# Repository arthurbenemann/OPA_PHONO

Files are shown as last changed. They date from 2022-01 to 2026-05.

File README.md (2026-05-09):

# OPA_PHONO

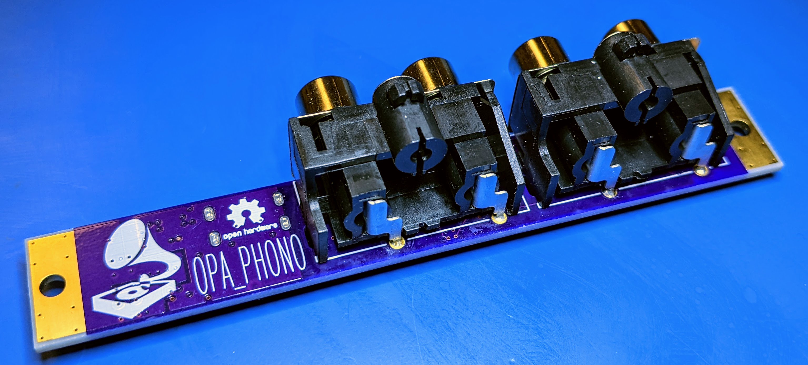
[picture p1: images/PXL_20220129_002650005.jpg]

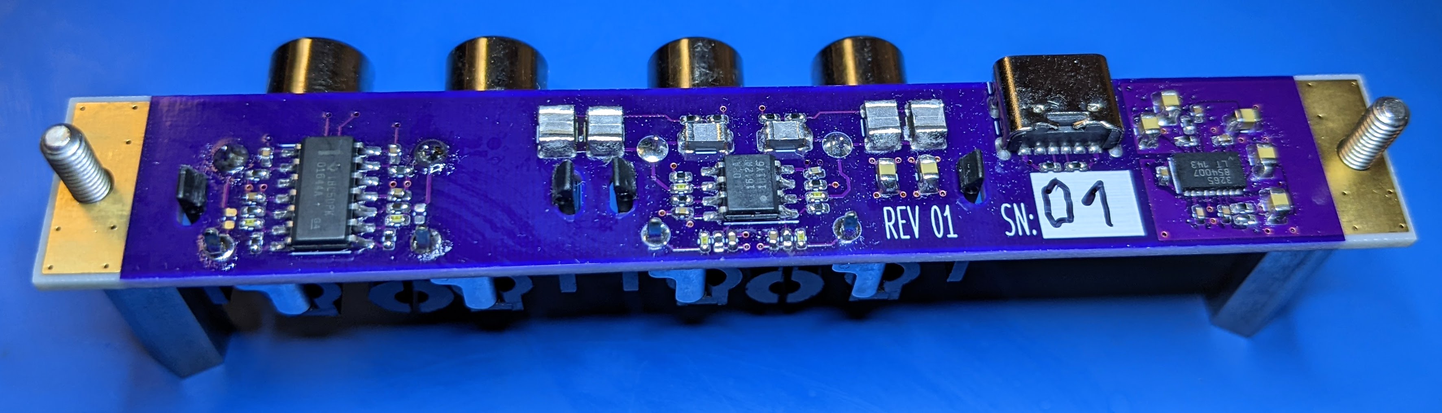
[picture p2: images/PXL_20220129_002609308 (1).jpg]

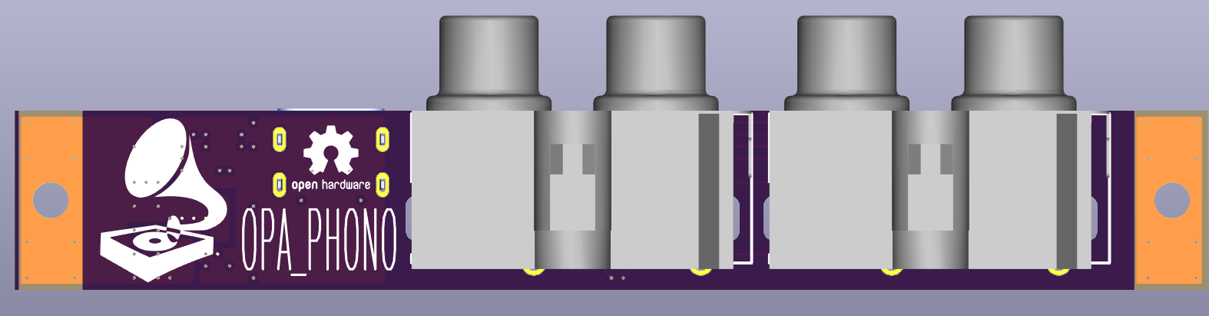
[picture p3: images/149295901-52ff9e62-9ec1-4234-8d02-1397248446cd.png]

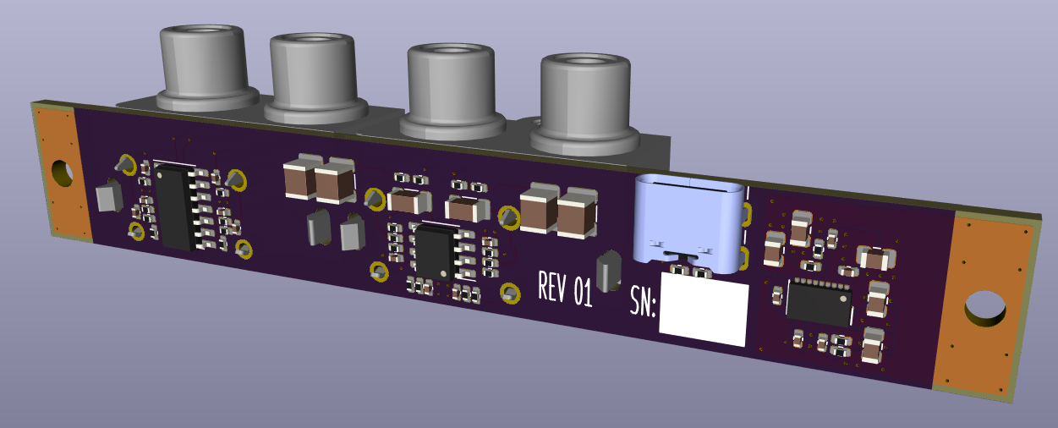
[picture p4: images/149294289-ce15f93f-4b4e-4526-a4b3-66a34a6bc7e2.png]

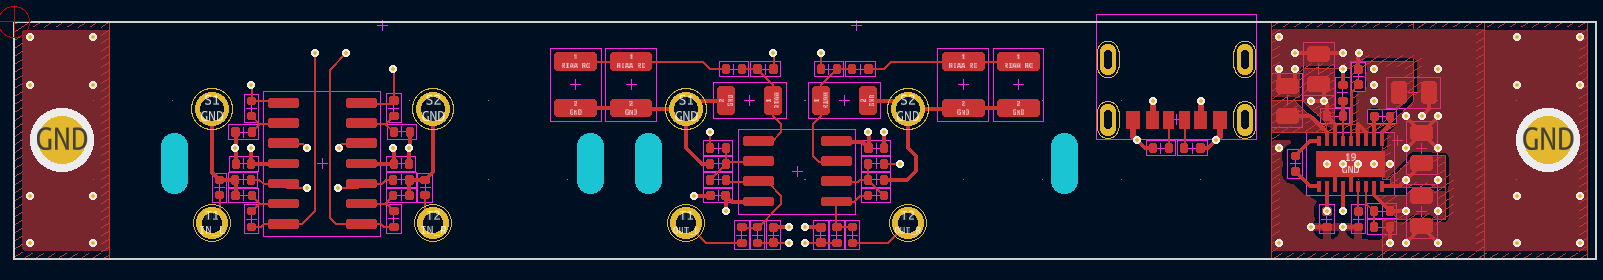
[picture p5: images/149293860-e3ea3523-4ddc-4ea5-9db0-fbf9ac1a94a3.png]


## RIAA filter Simulation
Overall response with (blue) and without(green) cartridge model:
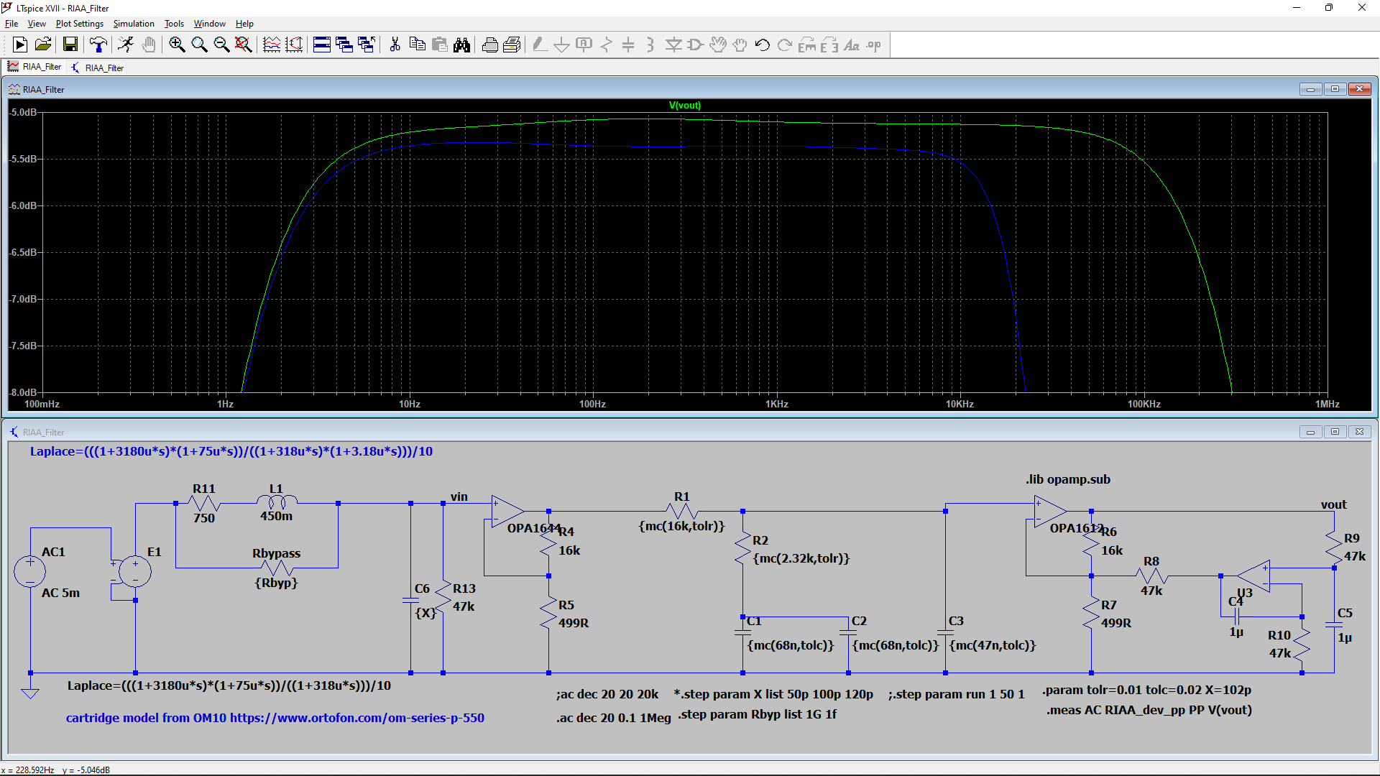
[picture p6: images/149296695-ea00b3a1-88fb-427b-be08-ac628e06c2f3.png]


RIAA Filter deviation assuming 2% capacitors and 1% resistors
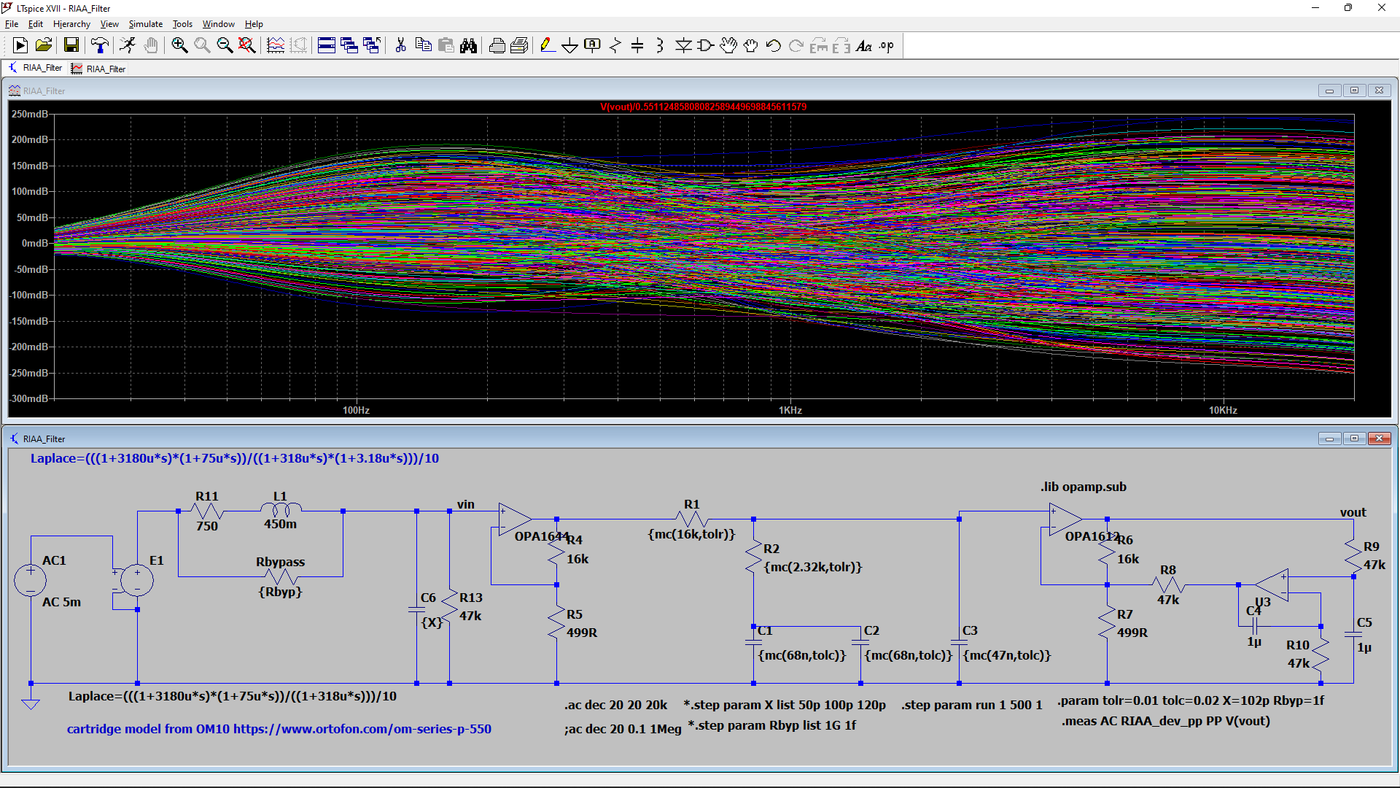
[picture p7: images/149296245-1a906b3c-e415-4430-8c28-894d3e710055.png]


## Mechanical Enclosure

### Hammond case
The CAD model is avaliable in Fusion360 at: https://a360.co/32rnA34.  I may design a faceplate PCB with graphics, but in the meantime the Hammond 1544L80 enclosure can be milled acording to the drawings at [OPA_PHONO_FACEPLATE.pdf](/Enclosure/OPA_PHONO_FACEPLATE.pdf). A compatible drawing with slighly larger holes, but more avaliable sizes is on the bottom drawing.

### 3D printed case
Mell, has created a 3d printed case for his build. Files stored under [Enclosure-3dprint/](./Enclosure-3dprint/)

## Measurements

**SN01** deviation from RIAA curve, based on measurements [SN01_REW.mdat](Measurements/SN01_REW.mdat). Note very close to noise floor at 15kHz, 60Hz hum and harmonics distorting measurement, low frequency behavior from testing equipment. 

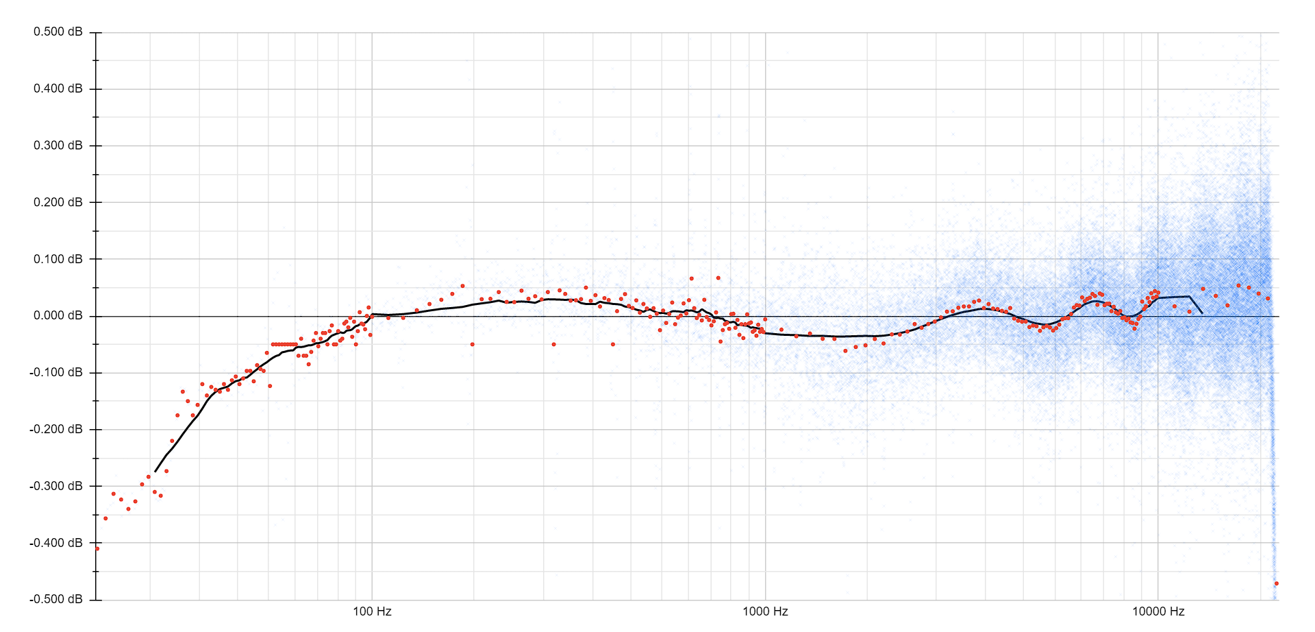
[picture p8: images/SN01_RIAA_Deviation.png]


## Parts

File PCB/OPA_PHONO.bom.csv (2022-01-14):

Designator | Description | MPN | Manufacturer | Qty
C2, C3, C8, C9 | CAP FILM 0.068UF 2% 16VDC 1210 | ECH-U1C683GX5 | Panasonic Electronic Components | 4
C4, C10 | CAP FILM 0.047UF 2% 16VDC 1206 | ECH-U1C473GX5 | Panasonic Electronic Components | 2
C5, C6, C11-C14, C16-C22 | CAP CER 1UF 25V X5R 0402 | GRM155R61E105KA12D | Murata Electronics | 13
C15, C23-C28 | CAP CER 10UF 16V X5R 0805 | GRM21BR61C106KE15L | Murata Electronics | 7
J1, J2 | CONN DUAL RCA JACK MONO 3.2MM R/A | PJRAS2X1S01X | Switchcraft Inc. | 2
J3 | CONN RCPT TYPE C 24POS SMD RA | UJC-HP-3-SMT-TR | CUI Devices | 1
N1 | BOX ALUM NATURAL 3.15"LX4.05"W | 1455L801 | Hammond Manufacturing | 1
R5, R17 | RES SMD 2.32K OHM 1% 1/16W 0402 | RT0402FRE072K32L | YAGEO | 2
R2, R4, R7, R14, R16, R19 | RES SMD 16K OHM 1% 1/16W 0402 | RT0402FRE0716KL | YAGEO | 6
R3, R6, R8, R12, R15, R24 | RES SMD 499R OHM 1% 1/16W 0402 | RT0402FRE07499RL | YAGEO | 6
R1, R9-R11, R13, R21-R23 | RES SMD 47K OHM 1% 1/16W 0402 | RT0402FRE0747KL | YAGEO | 8
R25, R28 | RES 20.5K OHM 1% 1/16W 0402 | RC0402FR-0720K5L | YAGEO | 2
R26, R27, R29, R30 | RES SMD 5.1K OHM 1% 1/16W 0402 | RC0402FR-075K1L | YAGEO | 4
U1 | IC AUDIO 4 CIRCUIT 14SOIC | OPA1644AID | Texas Instruments | 1
U2 | IC AUDIO 2 CIRCUIT 8SOIC | OPA1612AID | Texas Instruments | 1
U3 | IC REG CHARGE PUMP INV 18DFN | LTC3265EDHC#TRPBF | Analog Devices Inc. | 1

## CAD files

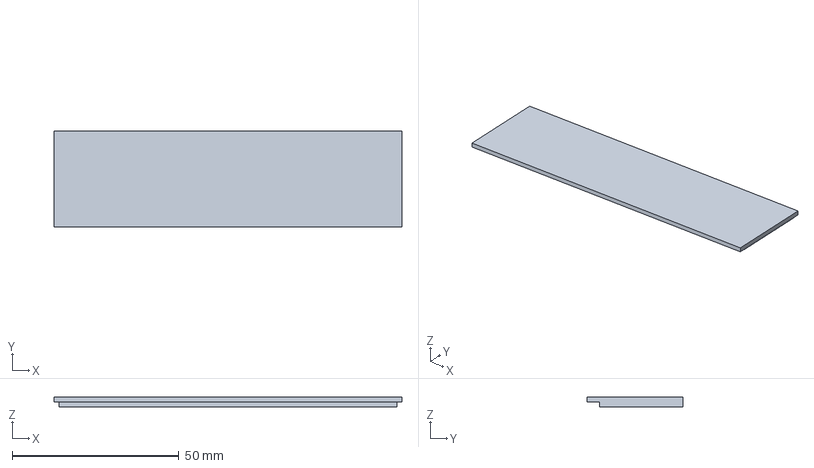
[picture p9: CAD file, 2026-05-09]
Enclosure-3dprint/Preamp Cover-Body.3mf
104.5 x 28.8 x 2.90 mm

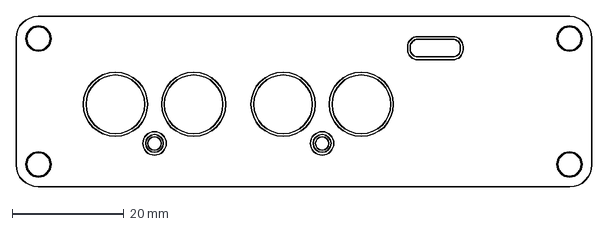
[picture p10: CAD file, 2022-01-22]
Enclosure/front_pannel.dxf
103.0 x 30.5 mm

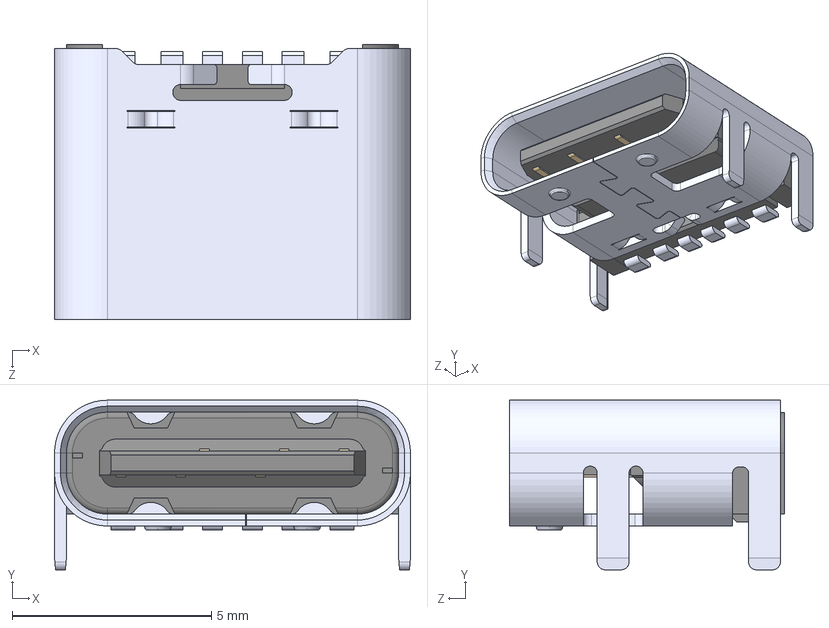
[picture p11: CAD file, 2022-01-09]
PCB/UJC-HP-3-SMT-TR.step
8.94 x 4.26 x 6.90 mm

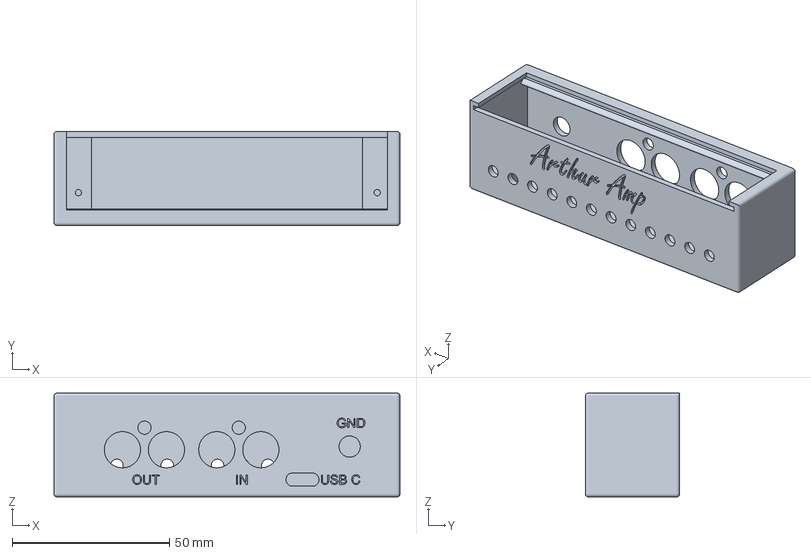
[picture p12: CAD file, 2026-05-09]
Enclosure-3dprint/Phono Preamp Box-Body.3mf
110.0 x 30.0 x 33.0 mm

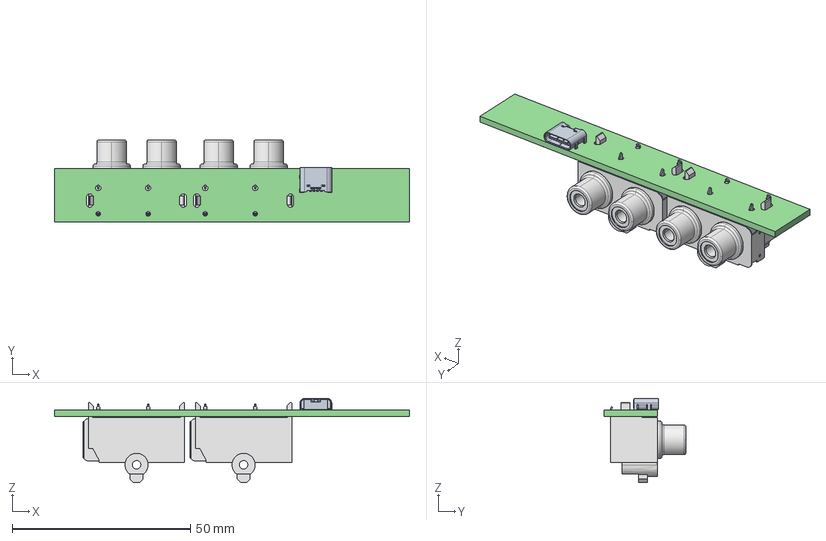
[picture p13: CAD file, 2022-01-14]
Enclosure/OPA_PHONO.step
99.5 x 23.0 x 23.6 mm
OPA_PHONO PCB

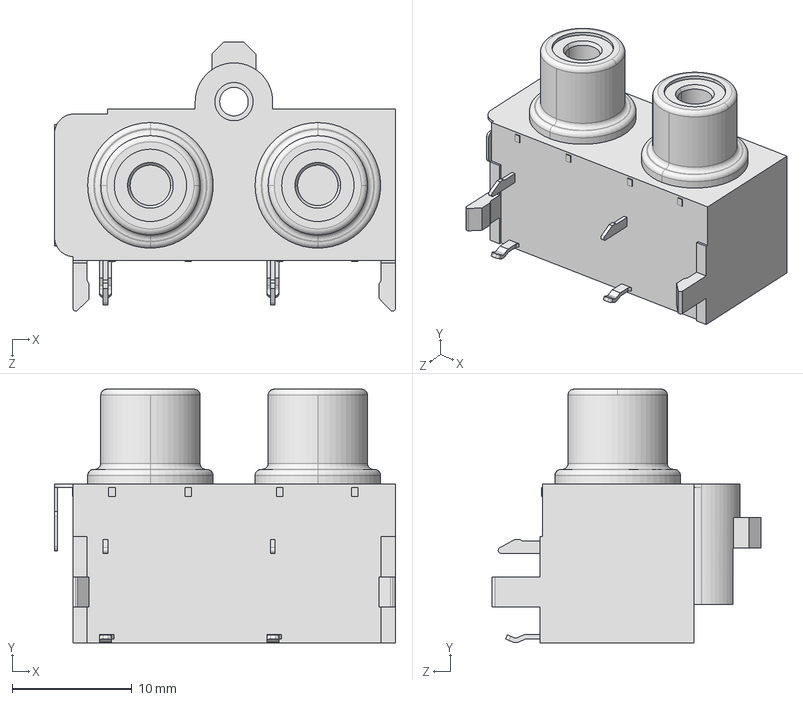
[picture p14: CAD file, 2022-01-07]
PCB/pjras2x1s_series.STEP
28.5 x 21.2 x 22.5 mm

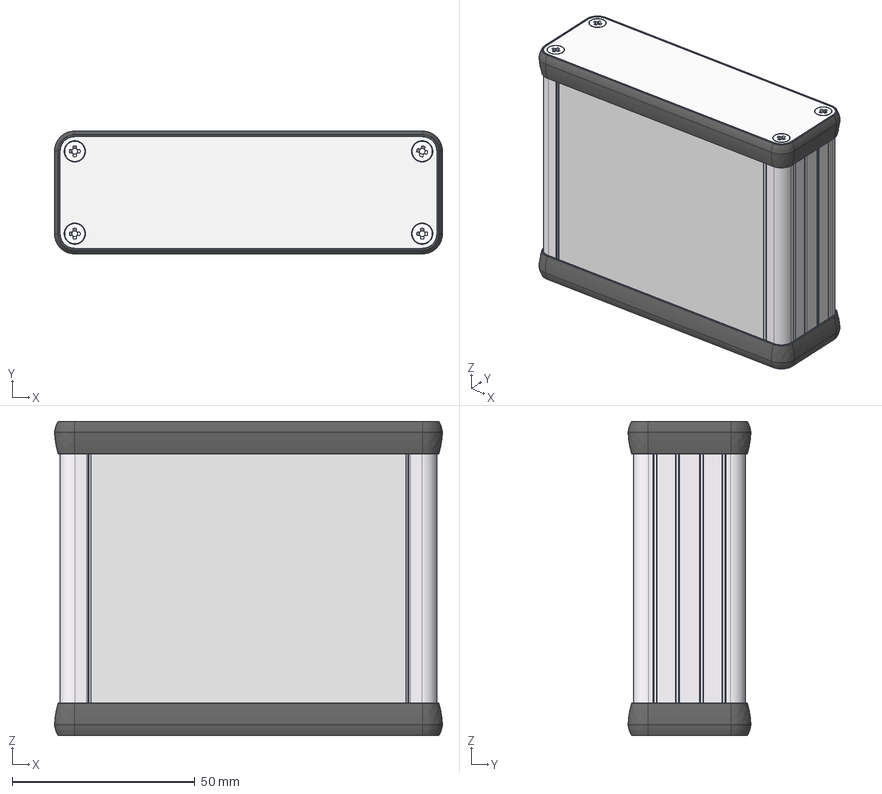
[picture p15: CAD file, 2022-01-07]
Enclosure/1455L801BU.stp
106.1 x 33.6 x 86.0 mm
L Extrusion 80mm
L Cap Extrusion 80mm
N Bezel x 2
N1 End Panel x 2
1455 screw x 8

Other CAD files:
Enclosure/OPA_PHONO.FCStd

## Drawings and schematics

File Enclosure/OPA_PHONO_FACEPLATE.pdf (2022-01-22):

71.86 4.16

# 47.76 ²².75

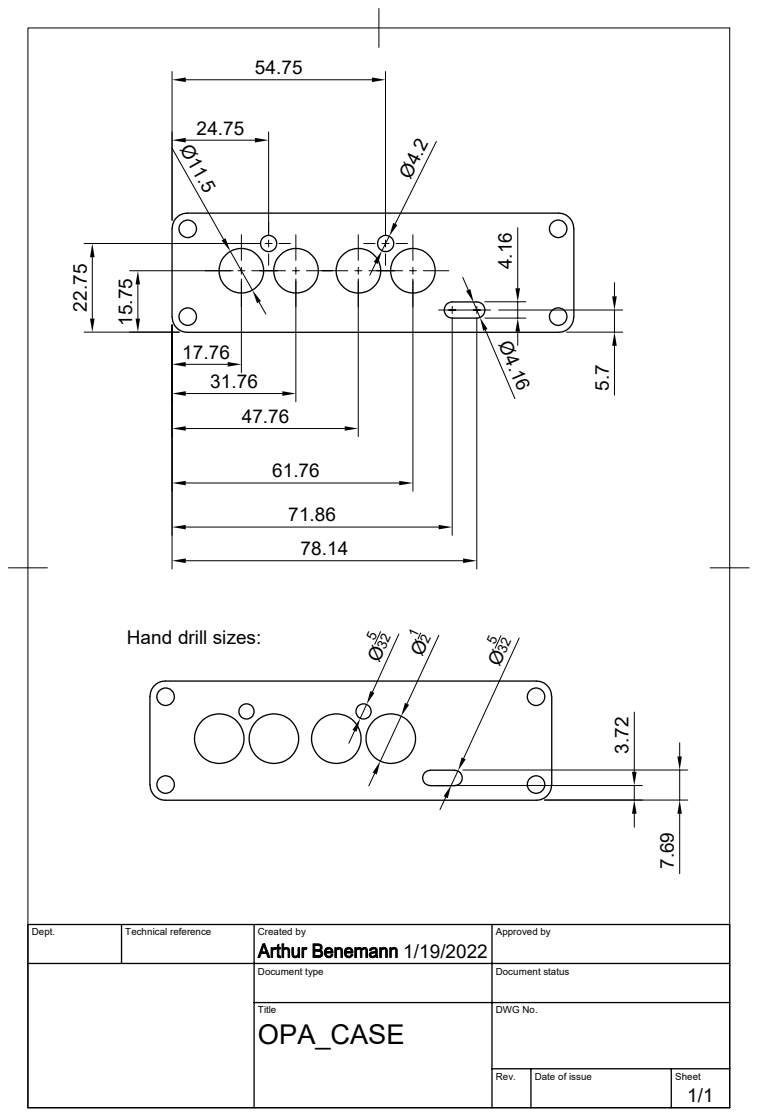
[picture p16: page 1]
Dept.; Technical reference; Created by; Approved by; Document type; Document status; Title; DWG No.; Rev.; Date of issue; Sheet; OPA_CASE

Hand drill sizes:

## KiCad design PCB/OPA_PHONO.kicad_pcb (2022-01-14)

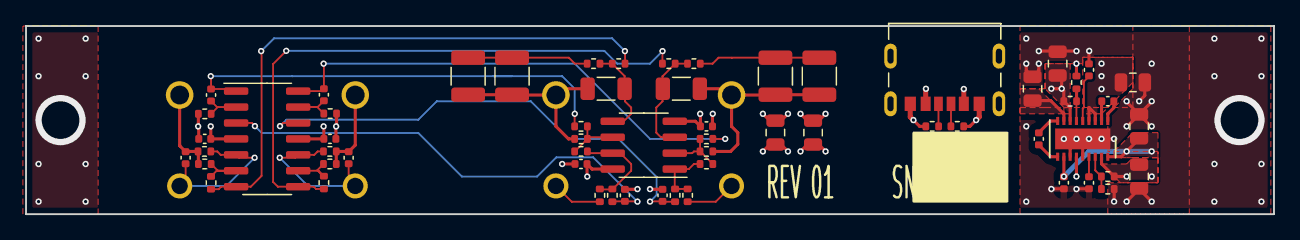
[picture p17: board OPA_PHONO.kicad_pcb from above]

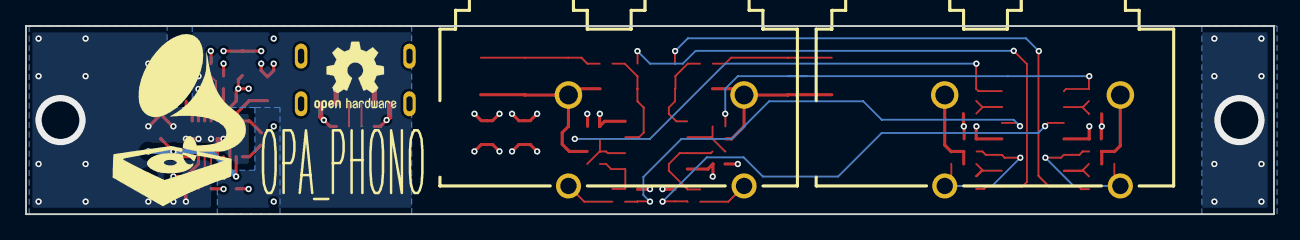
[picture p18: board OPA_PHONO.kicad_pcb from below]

Board: 4 copper layers, 99.5 x 15.0 mm, 62 parts (2 on the bottom side), 38 nets.

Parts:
C1, C7: NP; C_0402_1005Metric
C2, C3, C8, C9: 68n; C_1210_3225Metric
C4, C10: 47n; C_1206_3216Metric
C5, C6, C11, C12, C13, C14, C16, C17, C18, C19, C20, C21, C22: 1u; C_0402_1005Metric
C15, C23, C24, C25, C26, C27, C28: 10u; C_0805_2012Metric
J1, J2: PJRAS2X1S01X
J3: UJC-HP-3-SMT-TR; CUI_UJC-HP-3-SMT-TR
R1, R9, R10, R11, R13, R21, R22, R23: 47k; R_0402_1005Metric
R2, R4, R7, R14, R16, R19: 16k; R_0402_1005Metric
R3, R6, R8, R12, R15, R24: 499R; R_0402_1005Metric
R5, R17: 2.32k; R_0402_1005Metric
R25, R28: 20.5k; R_0402_1005Metric
R26, R27, R29, R30: 5.1k; R_0402_1005Metric
U1: OPA1644AxD; SOIC-14_3.9x8.7mm_P1.27mm
U2: OPA1612AxD; SOIC-8_3.9x4.9mm_P1.27mm
U3: LTC3265xDHC; DFN-18-1EP_3x5mm_P0.5mm_EP1.66x4.4mm

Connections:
/CC1: J3.A5 (CC1), R30.1
/CC2: J3.B5 (CC2), R29.1
/IN_L: C7.1, J2.T1, R13.2, U1.5 (+)
/IN_R: C1.1, J2.T2, R1.2, U1.10 (+)
/LEFT/FB1: R14.2, R15.2, U1.6 (-)
/LEFT/FB2: R6.2, R19.2, R21.2, U2.6 (-)
/LEFT/FBTRIM: C11.2, R22.2, U1.2 (-)
/LEFT/OUT1: R14.1, R16.2, U1.7
/LEFT/OUT2: R19.1, R23.1, R24.1, U2.7
/LEFT/OUT_RC: C12.1, R23.2, U1.3 (+)
/LEFT/RIAA: C10.1, R16.1, R17.2, U2.5 (+)
/LEFT/RIAA_RC: C8.1, C9.1, R17.1
/LEFT/TRIM: C11.1, R21.1, U1.1
/OUT_L: J1.T1, R24.2
/OUT_R: J1.T2, R12.2
/POWER/+6V: C15.2, C19.2, C21.2, C27.2, R25.1, U1.4 (V+), U2.8 (V+), U3.17 (LDOP)
/POWER/-6V: C20.1, C22.1, C25.1, C28.1, R28.2, U1.11 (V-), U2.4 (V-), U3.7 (LDON)
/POWER/ADJN: R27.2, R28.1, U3.6 (ADJN)
/POWER/ADJP: R25.2, R26.1, U3.16 (ADJP)
/POWER/BYPN: C18.1, U3.5 (BYPN)
/POWER/BYPP: C17.2, U3.15 (BYPP)
/POWER/CBSTN: C16.2, U3.1 (CBSTN)
/POWER/CBSTP: C16.1, U3.2 (CBSTP)
/POWER/CINVN: C14.1, U3.9 (CINVN)
/POWER/CINVP: C14.2, U3.10 (CINVP)
/POWER/VIN: C23.2, J3.A9 (VBUS), J3.B9 (VBUS), U3.3 (VINP), U3.4 (ENN), U3.13 (ENP)
/POWER/VOUTN: C24.2, U3.8 (VOUTN)
/POWER/VOUTP: C13.2, C26.2, U3.11 (VINN), U3.18 (VOUTP)
/RIGHT/FB1: R2.2, R3.2, U1.9 (-)
/RIGHT/FB2: R7.2, R8.2, R9.2, U2.2 (-)
/RIGHT/FBTRIM: C5.2, R10.2, U1.13 (-)
/RIGHT/OUT1: R2.1, R4.2, U1.8
/RIGHT/OUT2: R7.1, R11.1, R12.1, U2.1
/RIGHT/OUT_RC: C6.1, R11.2, U1.12 (+)
/RIGHT/RIAA: C4.1, R4.1, R5.2, U2.3 (+)
/RIGHT/RIAA_RC: C2.1, C3.1, R5.1
/RIGHT/TRIM: C5.1, R9.1, U1.14
GND: C1.2, C2.2, C3.2, C4.2, C6.2, C7.2, C8.2, C9.2, C10.2, C12.2, C13.1, C15.1, C17.1, C18.2, C19.1, C20.2, C21.1, C22.2, C23.1, C24.1, C25.2, C26.1, C27.1, C28.2, J1.S1, J1.S2, J2.S1, J2.S2, J3.A12 (GND), J3.B12 (GND), R1.1, R3.1, R6.1, R8.1, R10.1, R13.1, R15.1, R22.1, R26.2, R27.1, R29.2, R30.2, U3.12 (RT), U3.14 (MODE), U3.19 (GND)

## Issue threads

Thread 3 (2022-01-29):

Mechanical changes for rev2

arthurbenemann, 2022-01-29:
- USB connector needs relocation, current too far behind bezel,
- and pcb not constrained in that area (USB)
- need a grounding point on chassis

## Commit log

2022-01-08 CHANGE POWER SUPPLY
    [OPA_PHONO.kicad_pcb, OPA_PHONO.kicad_sch, POWER.kicad_sch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]
2022-01-09 update layout
    [OPA_PHONO.kicad_pcb, OPA_PHONO.kicad_sch, POWER.kicad_sch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]
2022-01-09 add usb c connector
    [OPA_PHONO.kicad_pcb, OPA_PHONO.kicad_sch, POWER.kicad_sch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]
2022-01-09 Update component fields
    [OPA_PHONO.kicad_pcb, OPA_PHONO.kicad_sch, POWER.kicad_sch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]
2022-01-09 routed all nets
    [OPA_PHONO.kicad_pcb, OPA_PHONO.kicad_sch, POWER.kicad_sch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]
2022-01-12 Clean DRC
    [OPA_PHONO.csv, OPA_PHONO.kicad_pcb, OPA_PHONO.kicad_sch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]
2022-01-13 simplify BOM
    [OPA_PHONO.kicad_pcb, OPA_PHONO.kicad_sch, POWER.kicad_sch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]
2022-01-13 Add graphics, simplify output resistor
    [OPA_PHONO.kicad_pcb, OPA_PHONO.kicad_sch, RIAA_PHONO.kicad_sch]
2022-01-13 change output resistor to 499R
    [OPA_PHONO.kicad_pcb, OPA_PHONO.kicad_sch, RIAA_PHONO.kicad_sch]
2022-01-14 Generate Gerbers
    [1455L801BU.stp, OPA_PHONO.FCStd, OPA_PHONO.bom.csv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]
2022-01-14 Organize files
    [OPA_PHONO.bom.csv, OPA_PHONO.csv, OPA_PHONO.kicad_pcb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]
2022-01-22 add dxf for front pannel, and pcb file
    [OPA_PHONO.FCStd, PCB_faceplate.kicad_pcb, PCB_faceplate.kicad_sch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]
2022-01-22 add milling pdf
